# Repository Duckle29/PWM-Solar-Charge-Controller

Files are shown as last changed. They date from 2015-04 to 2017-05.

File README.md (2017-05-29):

# PWM-Solar-Charge-Controller

I have decided to revive this project again. It's gonna be brought back as the PWM10, as It'll be designed to handle 10A, which is a little over a 140W panel.
The Rev2 files are designed using KiCAD

This is an attempt at making an Arduino powered PWM solar charge controller.

The design of this controller is heavily based on Julian Iletts PWM5 controller, which he sadly discontinued.
He however makes some interesting Youtube videos.

  * [Website](http://256.co.uk)
  * [Yoututbe](https://www.youtube.com/user/julius256)

This is **not** done, and there is no protection added to the board as of yet.
This first revision is simply as complete as I could make it, before my patience ran out for that day.
I might very well add the last few bits and bops within a few days.

### No Firmware has been written for this board as of yet
And as such, features and implementations of the hardware has yet to be decided.

### What is special about this spin-off of the PWM5?
This board is:
  * Entirely Arduino compatible, as it uses an ATMega328P
  * Able to measure the voltage of *both* the battery and panel, allowing for alternative control algorithms
  * Fitted with a slot for an NRF24L01+ Transceiver, for sending all available data back and forth / control the PWM charge controller. (After flashing the boot-loader, the solder bridges should be shorted for this feature)
  * Fitted with an RGB LED, that can be controlled to display all sorts of different color combinations and patterns
  * Designed to be cheaply mass produced, with purely SMT parts except for the headers for ISP, NRF and FTDI.

### What needs to be done?
The following things need to be added:
  * Reverse polarity protection
  * Short circuit protection
  * A thorough check of the schematic and board. I slapped this together in one 8 hour sitting, so I'm bound to have missed something / messed something up
  * Firmware needs to be written
  * It needs to be tested in general.
  * Parts need to be checked for availability and pricing. If none are available in the used footprint, a substitute has to be found.

### Additional notes
If I decide the board is ready to go, I will order some assembled boards. If people are interested in some assembled boards, then comment in the issue that I opened for that purpose. I might order some home and send them to you for the price it cost me, and nothing more (that's assembled board cost + shipping)

### Renders:
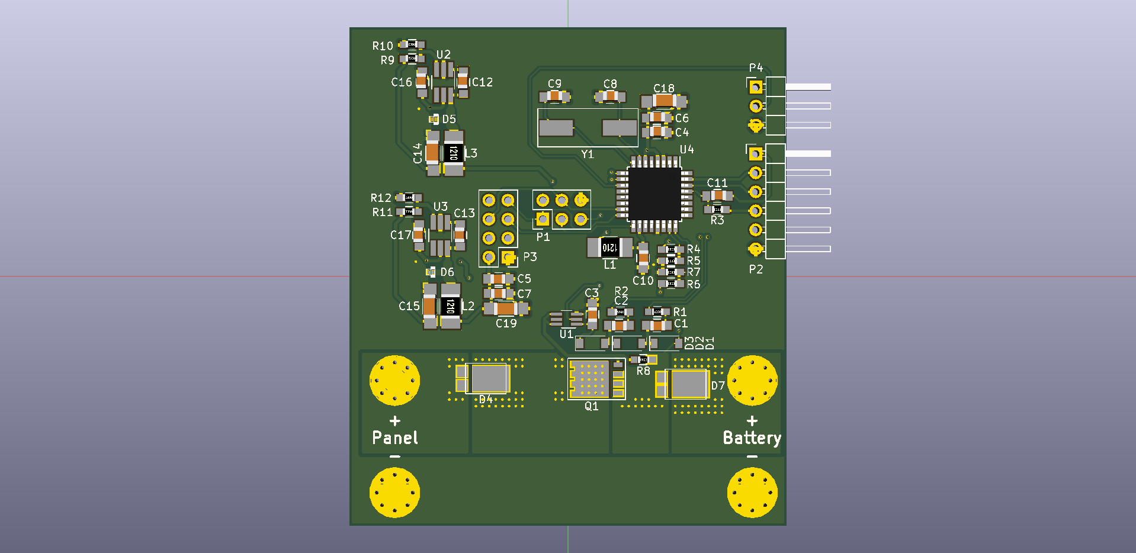
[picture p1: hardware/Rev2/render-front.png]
Front Render

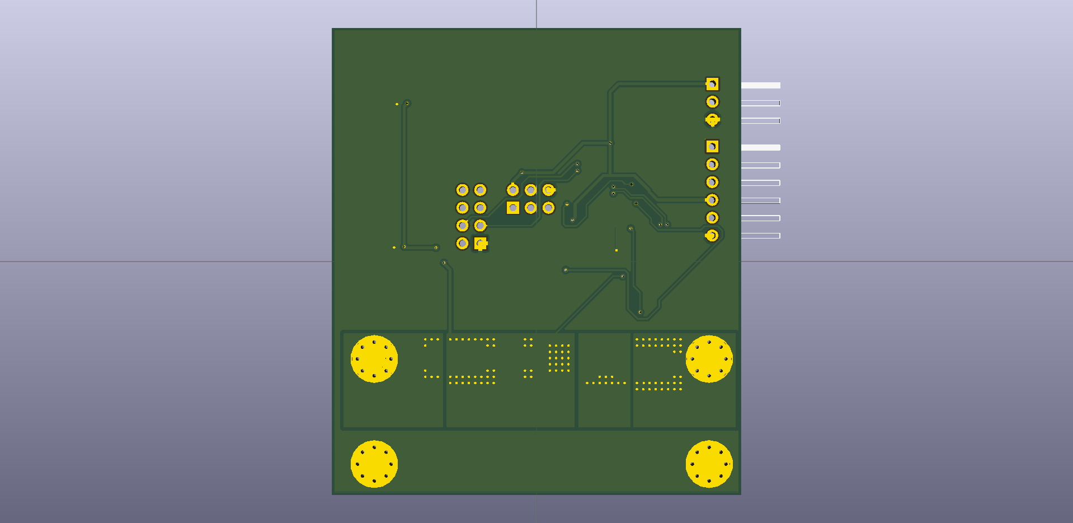
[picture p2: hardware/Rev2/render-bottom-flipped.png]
Flipped Bottom Render

Greetings!

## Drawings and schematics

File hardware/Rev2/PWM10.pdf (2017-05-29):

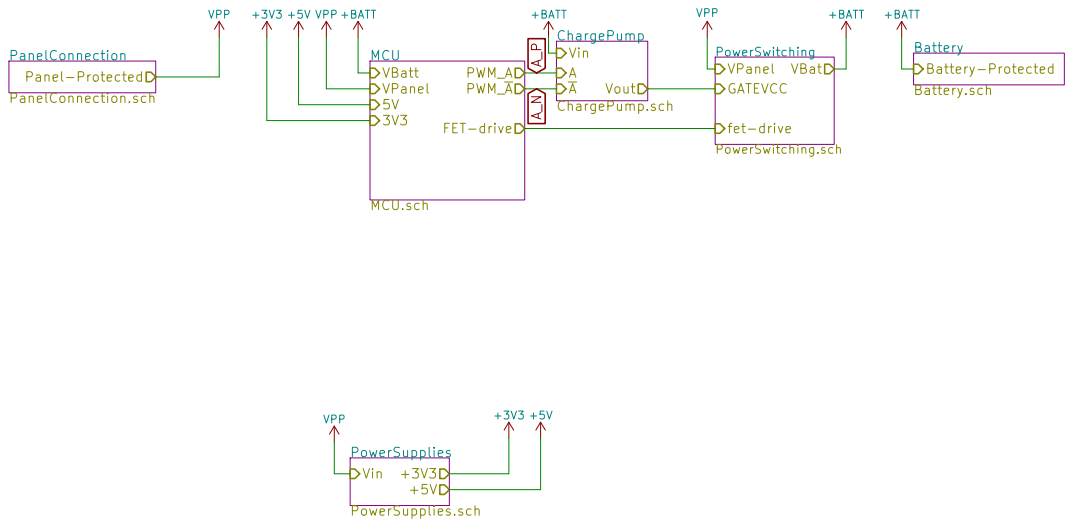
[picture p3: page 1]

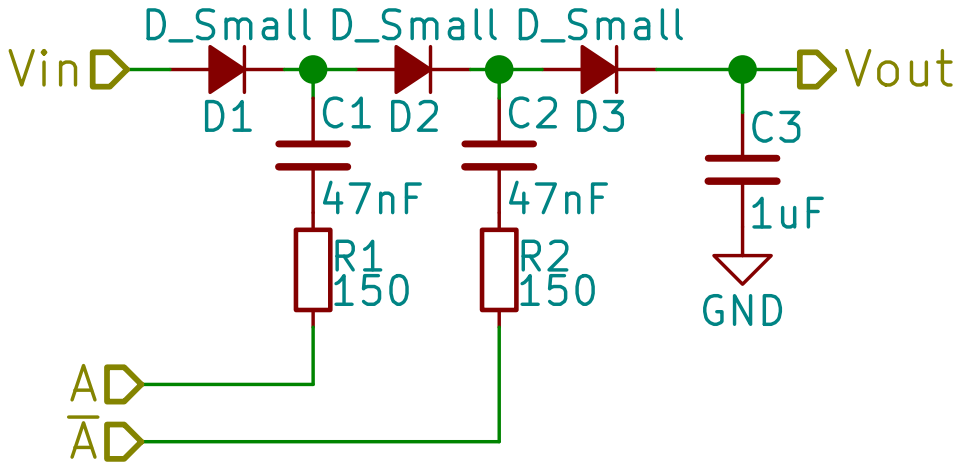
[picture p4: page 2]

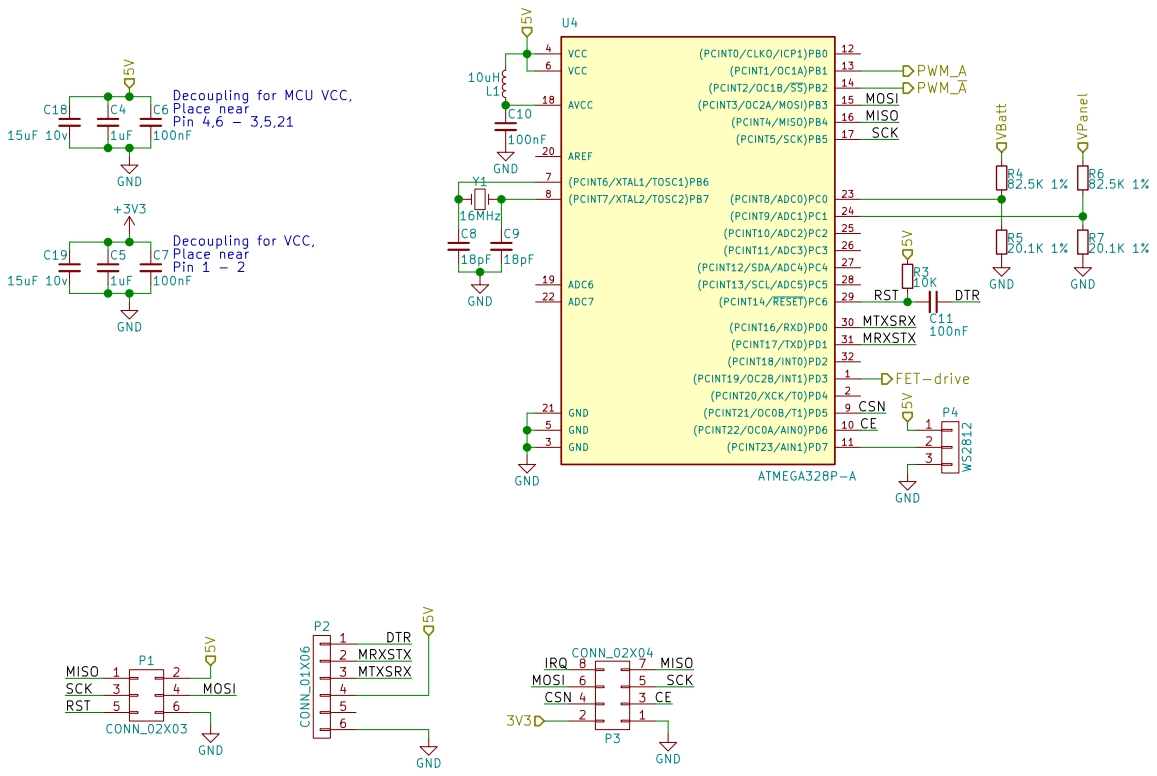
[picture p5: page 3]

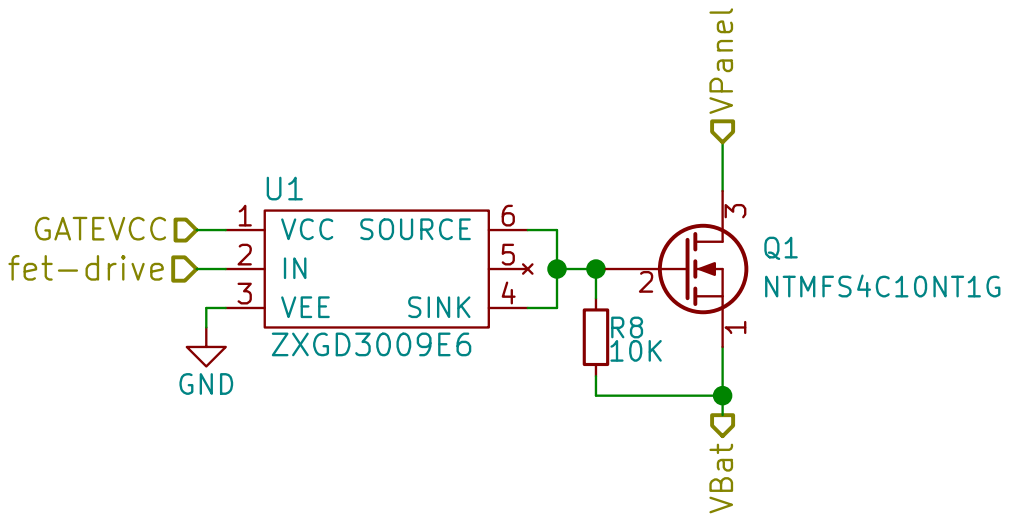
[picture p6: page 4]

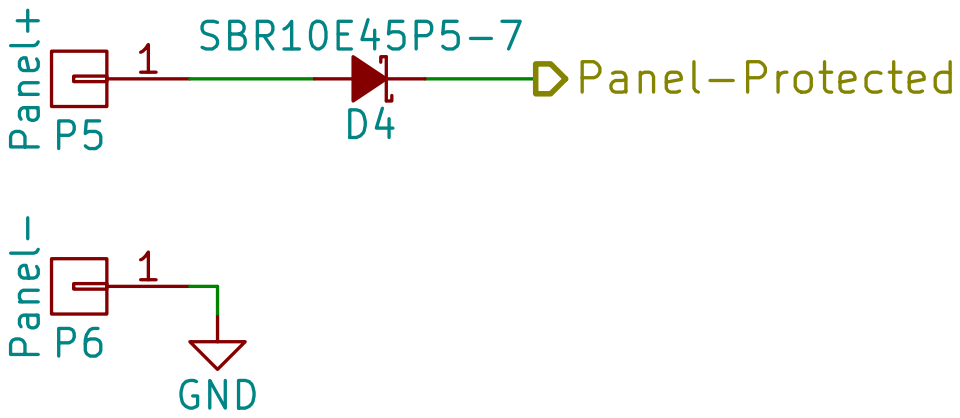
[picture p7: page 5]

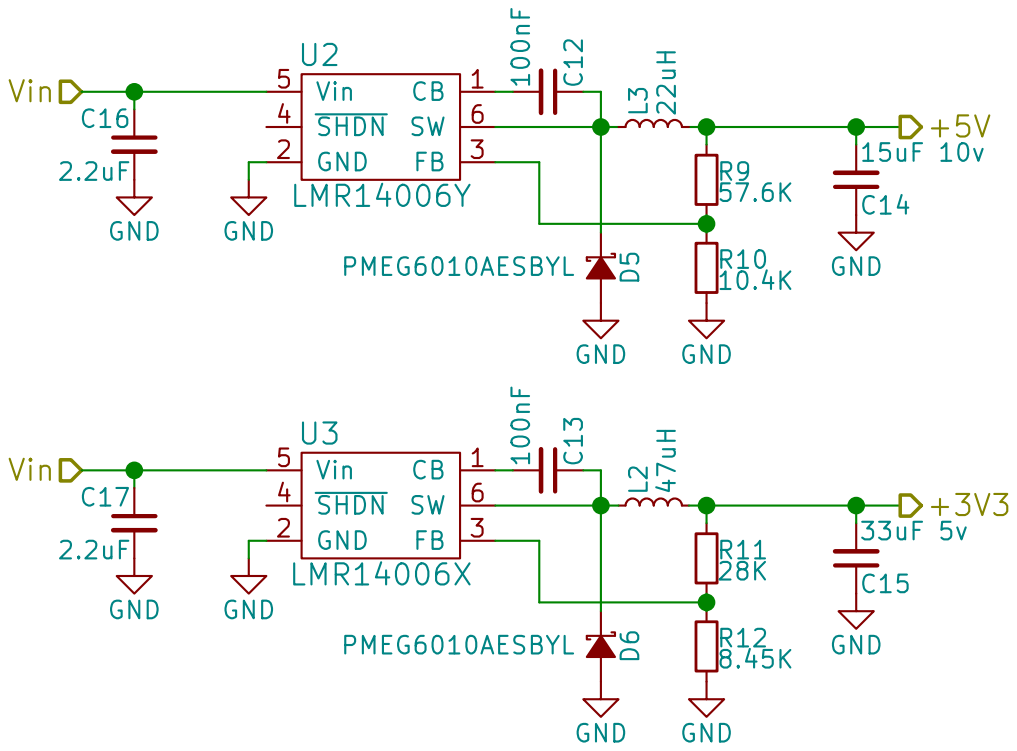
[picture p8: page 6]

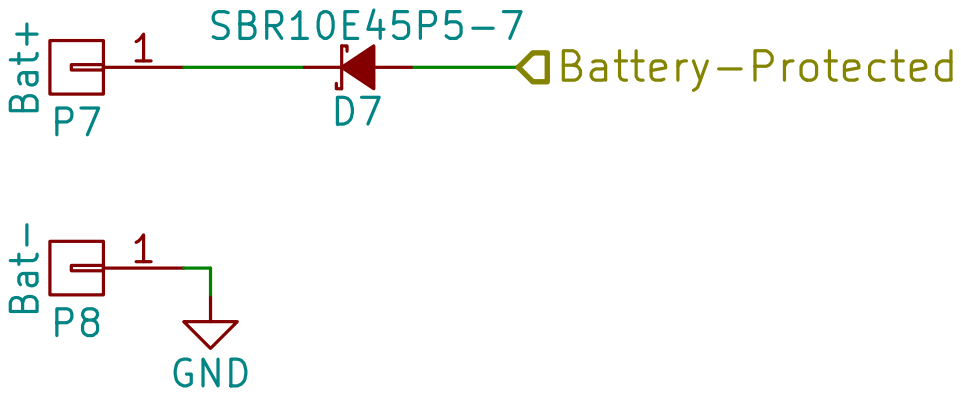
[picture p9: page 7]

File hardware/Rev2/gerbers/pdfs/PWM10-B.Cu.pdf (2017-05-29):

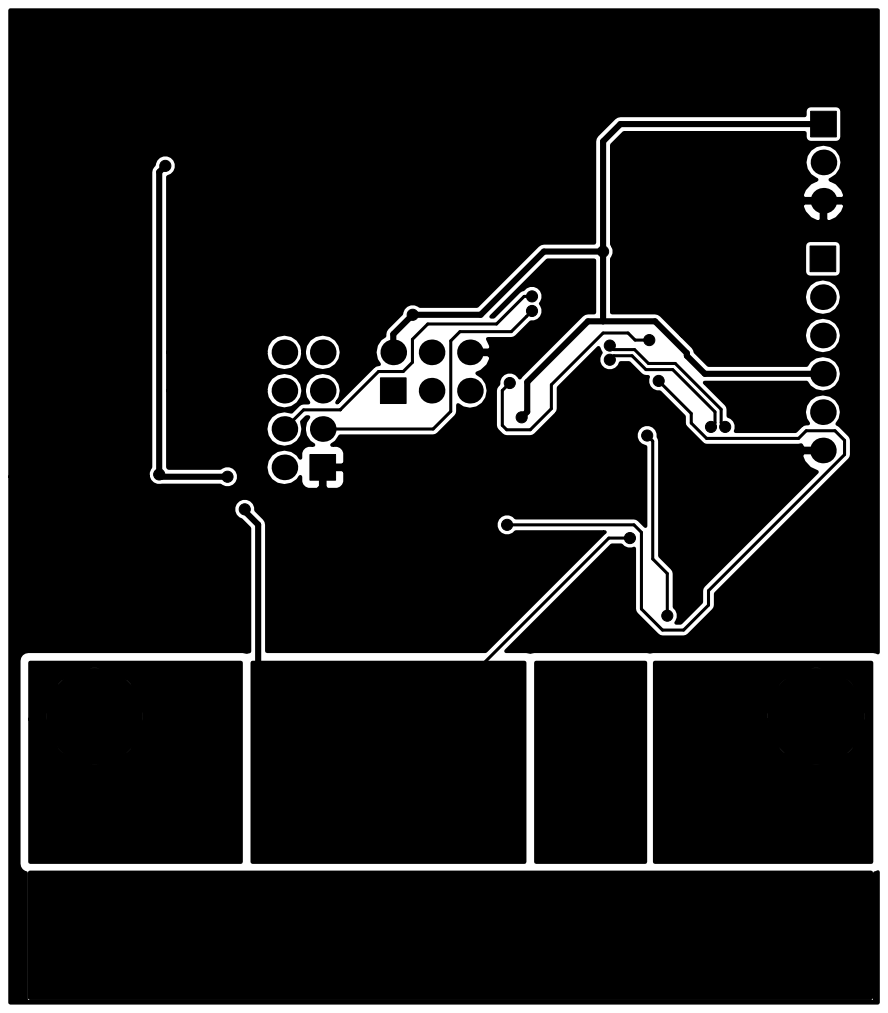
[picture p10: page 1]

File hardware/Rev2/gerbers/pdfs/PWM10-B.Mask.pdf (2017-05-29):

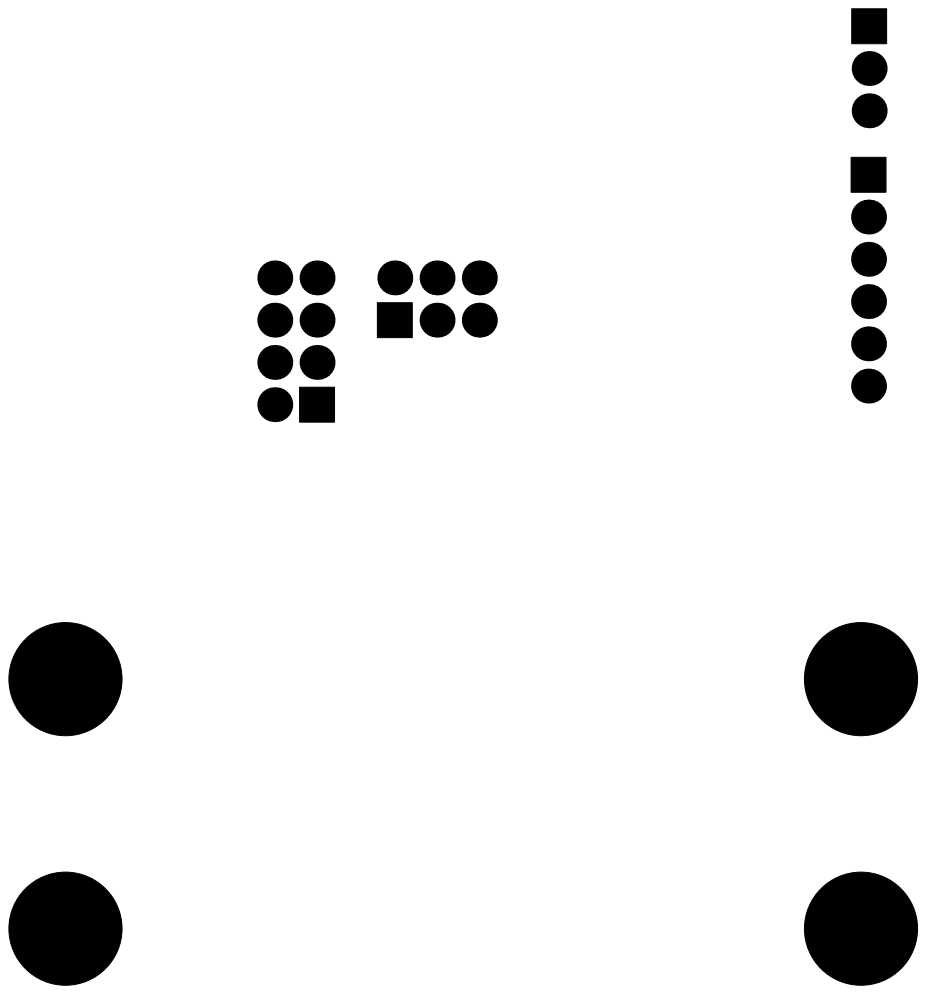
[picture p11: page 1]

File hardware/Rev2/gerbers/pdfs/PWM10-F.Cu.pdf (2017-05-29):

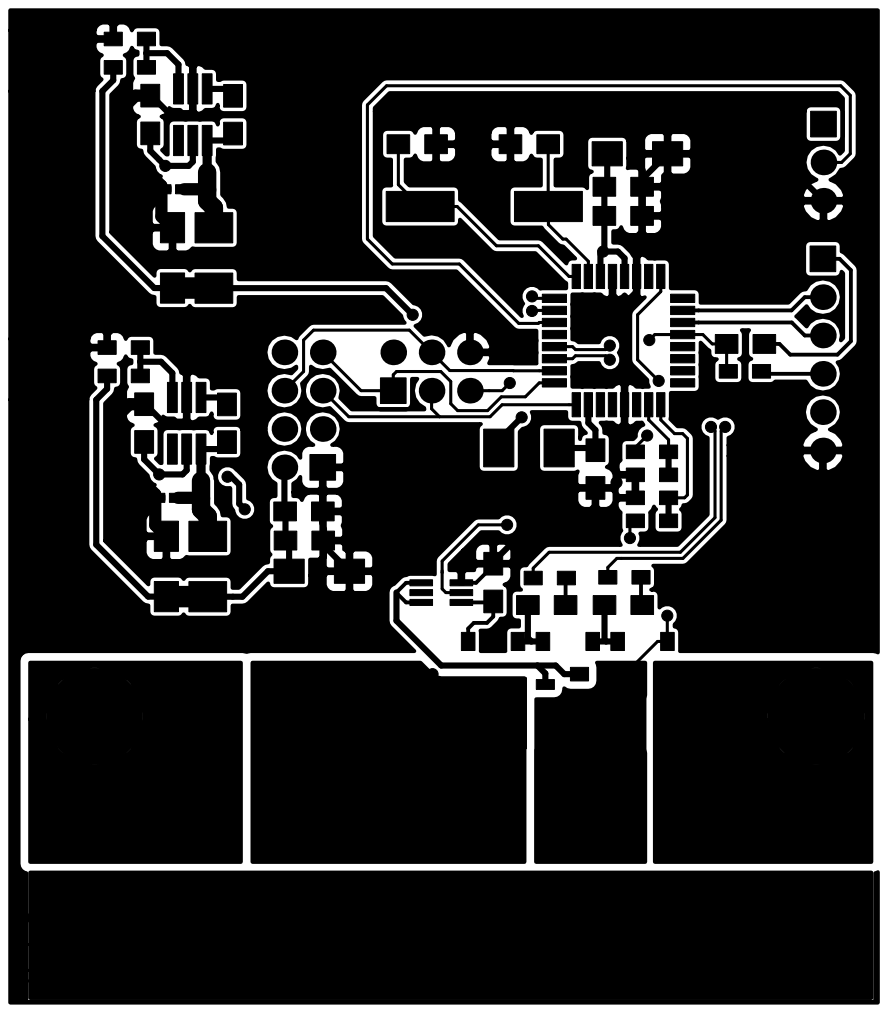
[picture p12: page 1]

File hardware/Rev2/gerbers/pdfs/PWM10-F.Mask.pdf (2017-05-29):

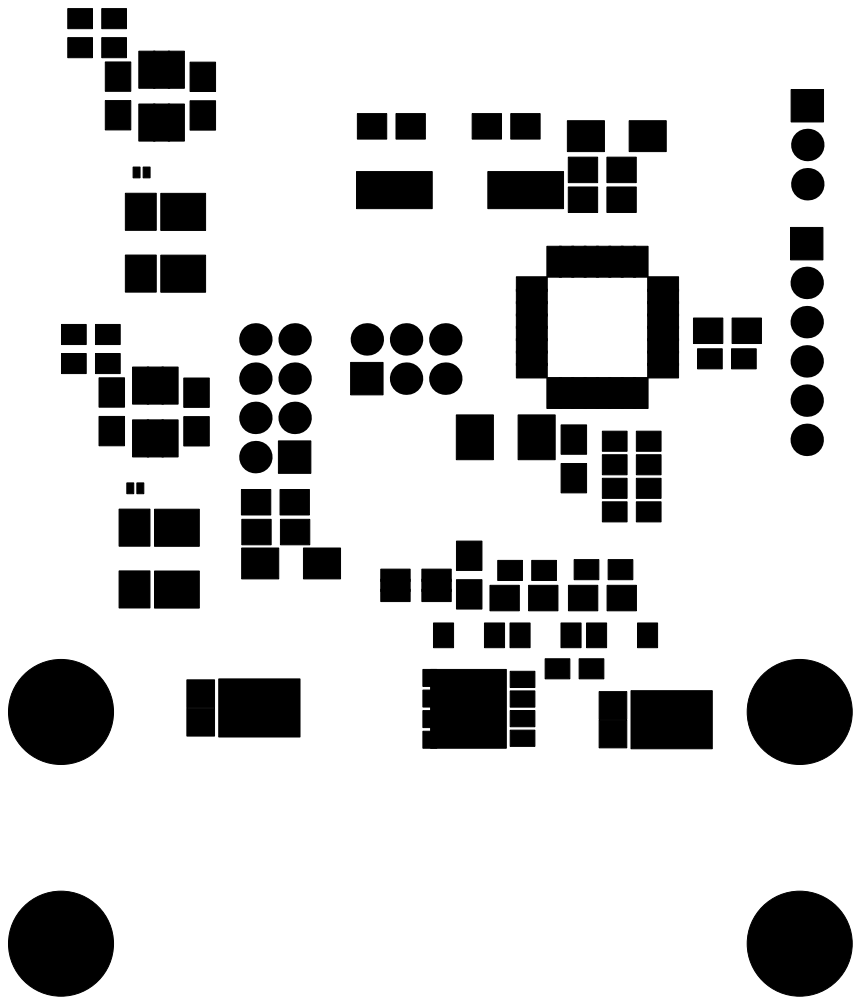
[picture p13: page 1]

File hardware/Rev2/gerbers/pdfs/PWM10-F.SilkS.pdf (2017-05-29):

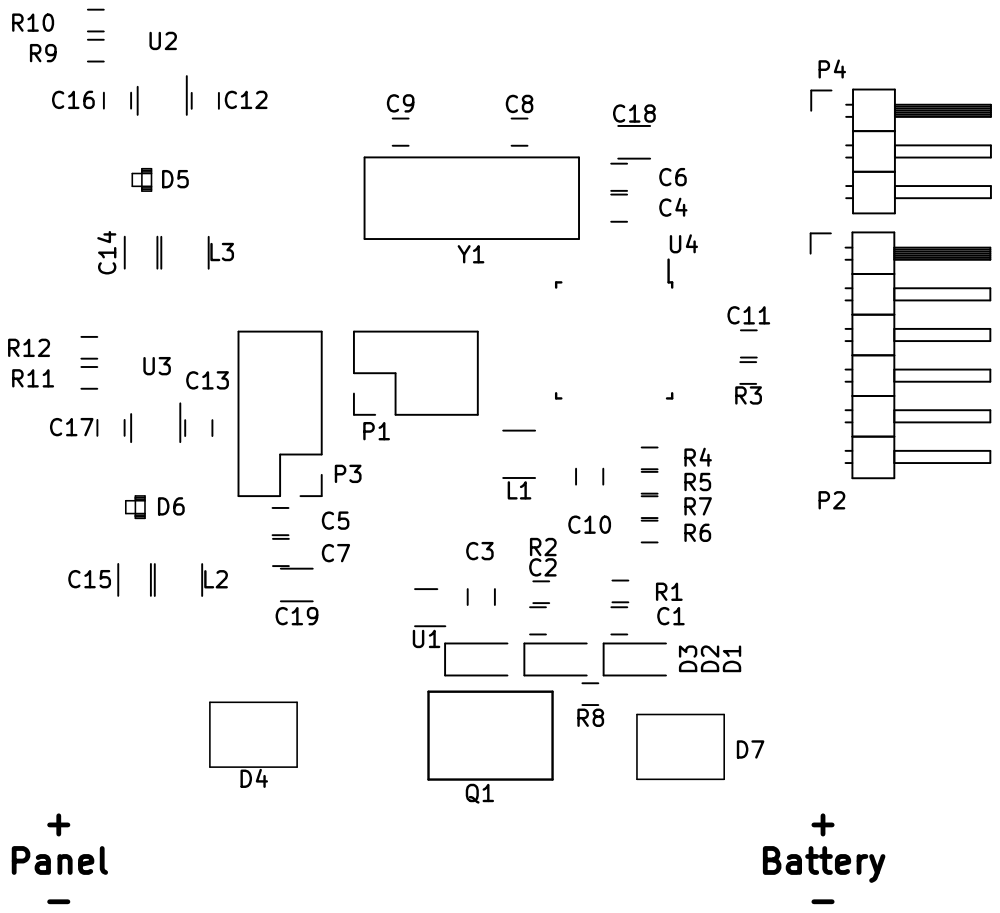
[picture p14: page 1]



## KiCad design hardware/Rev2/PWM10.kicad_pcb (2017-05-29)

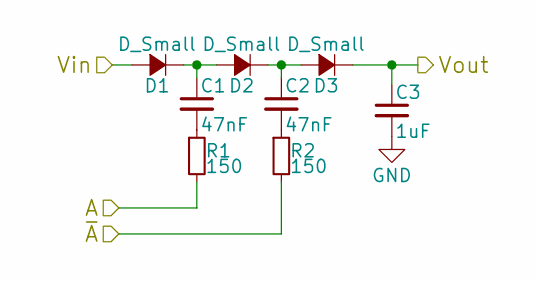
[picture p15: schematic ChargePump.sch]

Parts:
C1, C2: 47nF; C_0805_HandSoldering
C3: 1uF; C_0805_HandSoldering
D1, D2, D3: D_Small; D_SOD-123
R1, R2: 150; R_0603_HandSoldering

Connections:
+BATT: D1.2 (A); also elsewhere on the board
/PowerSwitching/GATEVCC: C3.1, D3.1 (K); also elsewhere on the board
A_N: R2.2; also elsewhere on the board
A_P: R1.2; also elsewhere on the board
GND: C3.2; also elsewhere on the board
unnamed: C1.1, D1.1 (K), D2.2 (A)
unnamed: C1.2, R1.1
unnamed: C2.1, D2.1 (K), D3.2 (A)
unnamed: C2.2, R2.1

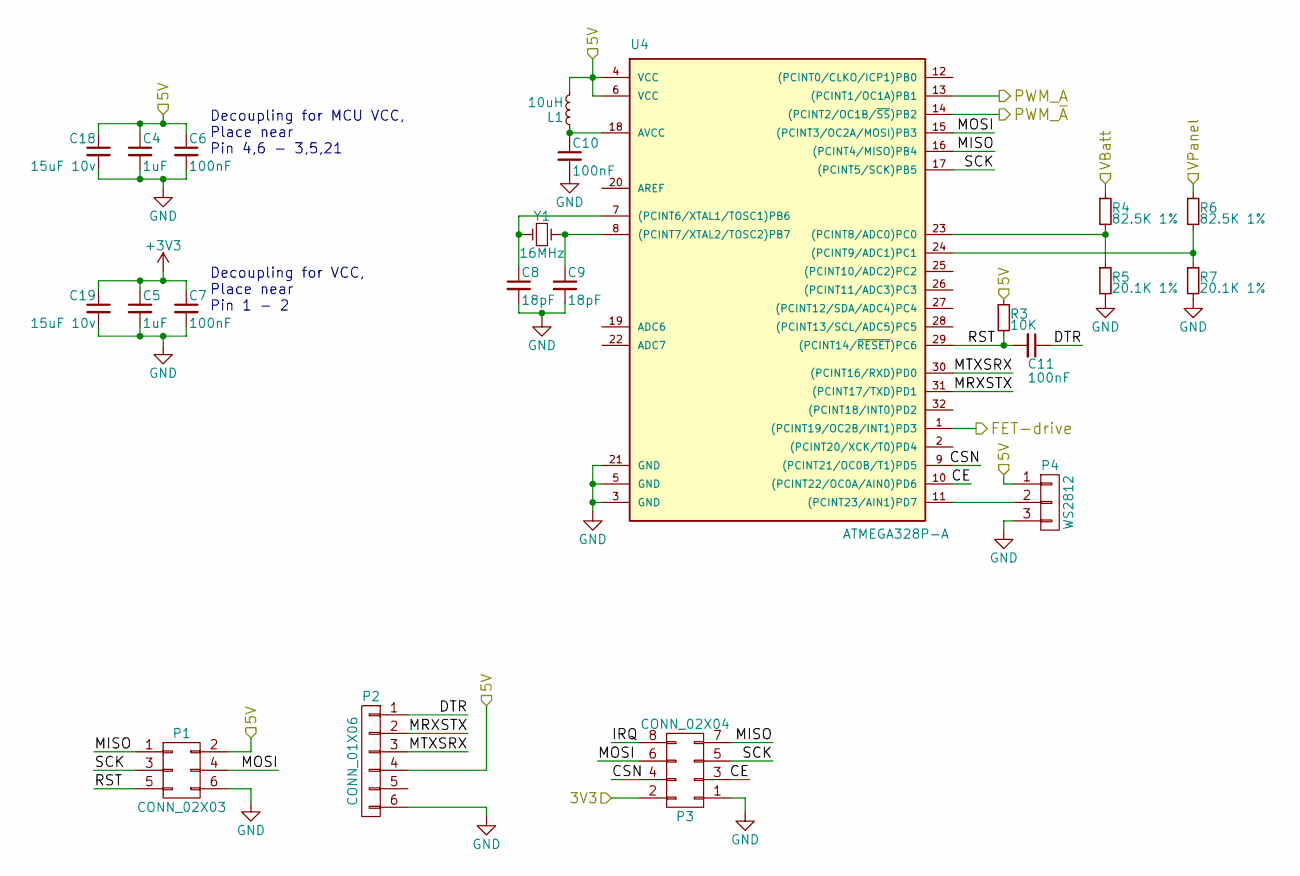
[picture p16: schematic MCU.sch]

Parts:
C4, C5: 1uF; C_0805_HandSoldering
C6, C7, C10, C11: 100nF; C_0805_HandSoldering
C8, C9: 18pF; C_0805_HandSoldering
C18, C19: 15uF 10v; C_1206_HandSoldering
L1: 10uH; R_1210_HandSoldering
P1: CONN_02X03; Pin_Header_Straight_2x03_Pitch2.54mm
P2: CONN_01X06; Pin_Header_Angled_1x06_Pitch2.54mm
P3: CONN_02X04; Pin_Header_Straight_2x04_Pitch2.54mm
P4: WS2812; Pin_Header_Angled_1x03_Pitch2.54mm
R3: 10K; R_0603_HandSoldering
R4, R6: 82.5K 1%; R_0603_HandSoldering
R5, R7: 20.1K 1%; R_0603_HandSoldering
U4: ATMEGA328P-A; TQFP-32_7x7mm_Pitch0.8mm
Y1: 16MHz; Crystal_SMD_HC49-SD

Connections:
+3V3: C5.1, C7.1, C19.1, P3.2; also elsewhere on the board
+5V: C4.1, C6.1, C18.1, L1.2, P1.2, P2.4, P4.1, R3.1, U4.4 (VCC), U4.6 (VCC); also elsewhere on the board
+BATT: R4.1; also elsewhere on the board
/MCU/CE: P3.3, U4.10 ((PCINT22/OC0A/AIN0)PD6)
/MCU/CSN: P3.4, U4.9 ((PCINT21/OC0B/T1)PD5)
/MCU/DTR: C11.1, P2.1
/MCU/FET-drive: U4.1 ((PCINT19/OC2B/INT1)PD3); also elsewhere on the board
/MCU/IRQ: P3.8
/MCU/MISO: P1.1, P3.7, U4.16 ((PCINT4/MISO)PB4)
/MCU/MOSI: P1.4, P3.6, U4.15 ((PCINT3/OC2A/MOSI)PB3)
/MCU/MRXSTX: P2.2, U4.31 ((PCINT17/TXD)PD1)
/MCU/MTXSRX: P2.3, U4.30 ((PCINT16/RXD)PD0)
/MCU/RST: C11.2, P1.5, R3.2, U4.29 ((PCINT14/~RESET~)PC6)
/MCU/SCK: P1.3, P3.5, U4.17 ((PCINT5/SCK)PB5)
A_N: U4.14 ((PCINT2/OC1B/~SS~)PB2); also elsewhere on the board
A_P: U4.13 ((PCINT1/OC1A)PB1); also elsewhere on the board
GND: C4.2, C5.2, C6.2, C7.2, C8.2, C9.2, C10.2, C18.2, C19.2, P1.6, P2.6, P3.1, P4.3, R5.2, R7.2, U4.3 (GND), U4.5 (GND), U4.21 (GND); also elsewhere on the board
unnamed: C8.1, U4.7 ((PCINT6/XTAL1/TOSC1)PB6), Y1.1
unnamed: C9.1, U4.8 ((PCINT7/XTAL2/TOSC2)PB7), Y1.2
unnamed: C10.1, L1.1, U4.18 (AVCC)
unnamed: P4.2, U4.11 ((PCINT23/AIN1)PD7)
unnamed: R4.2, R5.1, U4.23 ((PCINT8/ADC0)PC0)
unnamed: R6.2, R7.1, U4.24 ((PCINT9/ADC1)PC1)
VPP: R6.1; also elsewhere on the board

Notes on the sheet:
Decoupling for MCU VCC, Place near Pin 4,6 - 3,5,21
Decoupling for VCC, Place near Pin 1 - 2

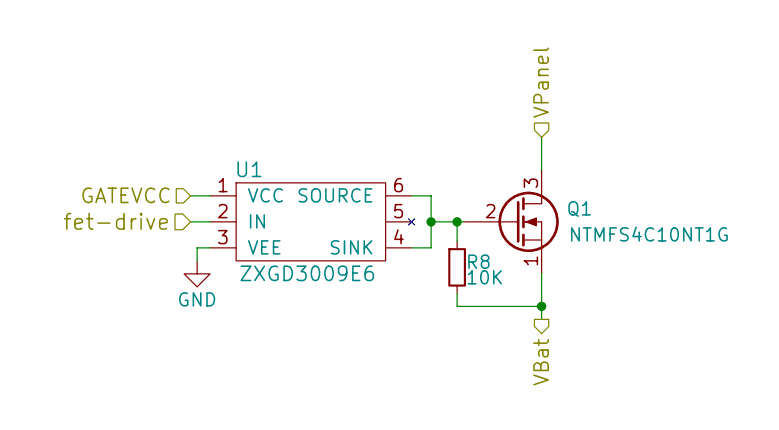
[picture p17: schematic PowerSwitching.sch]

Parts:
Q1: NTMFS4C10NT1G; PG-TDSON-8
R8: 10K; R_0603_HandSoldering
U1: ZXGD3009E6; SOT-363_SC-70-6_Handsoldering

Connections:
+BATT: Q1.1 (S), R8.2; also elsewhere on the board
/MCU/FET-drive: U1.2 (IN); also elsewhere on the board
/PowerSwitching/GATEVCC: U1.1 (VCC); also elsewhere on the board
GND: U1.3 (VEE); also elsewhere on the board
unnamed: Q1.2 (G), R8.1, U1.4 (SINK), U1.6 (SOURCE)
VPP: Q1.3 (D); also elsewhere on the board

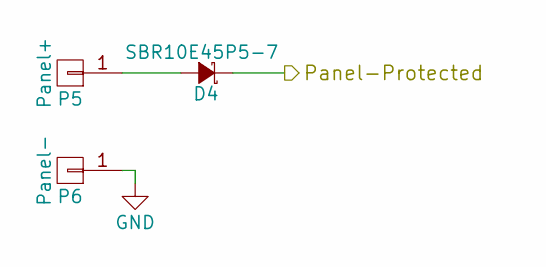
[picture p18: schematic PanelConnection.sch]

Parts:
D4: SBR10E45P5-7; PowerDI5
P5: Panel+; MountingHole_3.2mm_M3_Pad_Via
P6: Panel-; MountingHole_3.2mm_M3_Pad_Via

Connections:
GND: P6.1; also elsewhere on the board
unnamed: D4.2 (A), P5.1
VPP: D4.1 (K); also elsewhere on the board

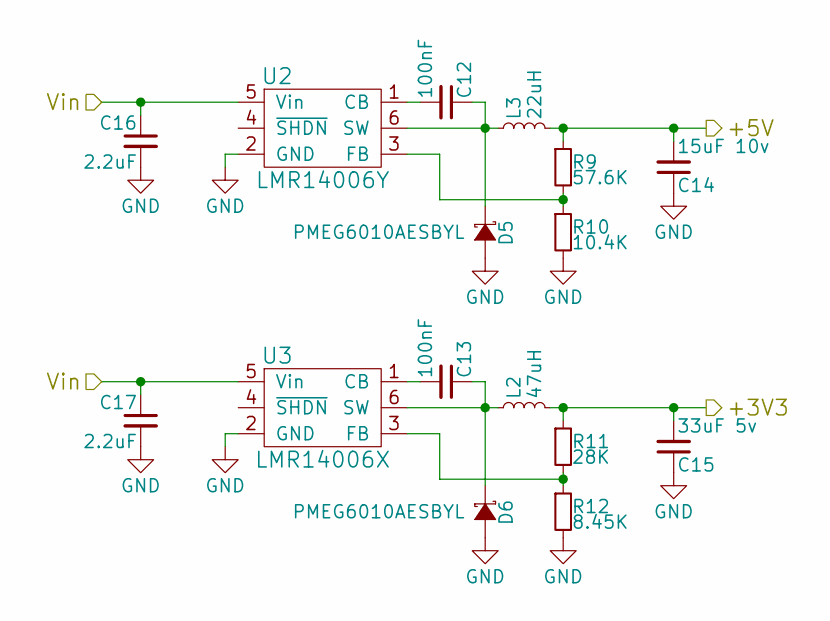
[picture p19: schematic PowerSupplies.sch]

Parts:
C12, C13: 100nF; C_0805_HandSoldering
C14: 15uF 10v; C_1206_HandSoldering
C15: 33uF 5v; C_1206_HandSoldering
C16, C17: 2.2uF; C_0805_HandSoldering
D5, D6: PMEG6010AESBYL; SOD-993
L2: 47uH; R_1210_HandSoldering; Part CBC3225T470MR
L3: 22uH; R_1210_HandSoldering; Part CBC3225T220MR
R9: 57.6K; R_0603_HandSoldering
R10: 10.4K; R_0603_HandSoldering
R11: 28K; R_0603_HandSoldering
R12: 8.45K; R_0603_HandSoldering
U2: LMR14006Y; TSOT-23-6_MK06A_HandSoldering
U3: LMR14006X; TSOT-23-6_MK06A_HandSoldering

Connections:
+3V3: C15.2, L2.2, R11.1; also elsewhere on the board
+5V: C14.2, L3.2, R9.1; also elsewhere on the board
GND: C14.1, C15.1, C16.2, C17.2, D5.2 (A), D6.2 (A), R10.2, R12.2, U2.2 (GND), U3.2 (GND); also elsewhere on the board
unnamed: C12.1, D5.1 (K), L3.1, U2.6 (SW)
unnamed: C12.2, U2.1 (CB)
unnamed: C13.1, D6.1 (K), L2.1, U3.6 (SW)
unnamed: C13.2, U3.1 (CB)
unnamed: R9.2, R10.1, U2.3 (FB)
unnamed: R11.2, R12.1, U3.3 (FB)
VPP: C16.1, C17.1, U2.5 (Vin), U3.5 (Vin); also elsewhere on the board

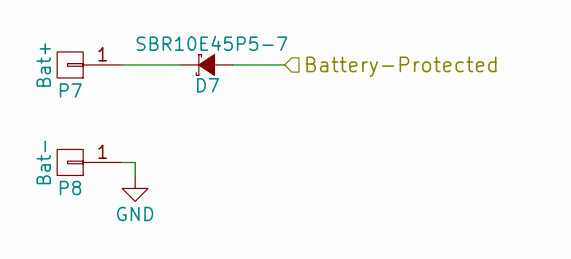
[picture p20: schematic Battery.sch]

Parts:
D7: SBR10E45P5-7; PowerDI5
P7: Bat+; MountingHole_3.2mm_M3_Pad_Via
P8: Bat-; MountingHole_3.2mm_M3_Pad_Via

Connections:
+BATT: D7.2 (A); also elsewhere on the board
GND: P8.1; also elsewhere on the board
unnamed: D7.1 (K), P7.1

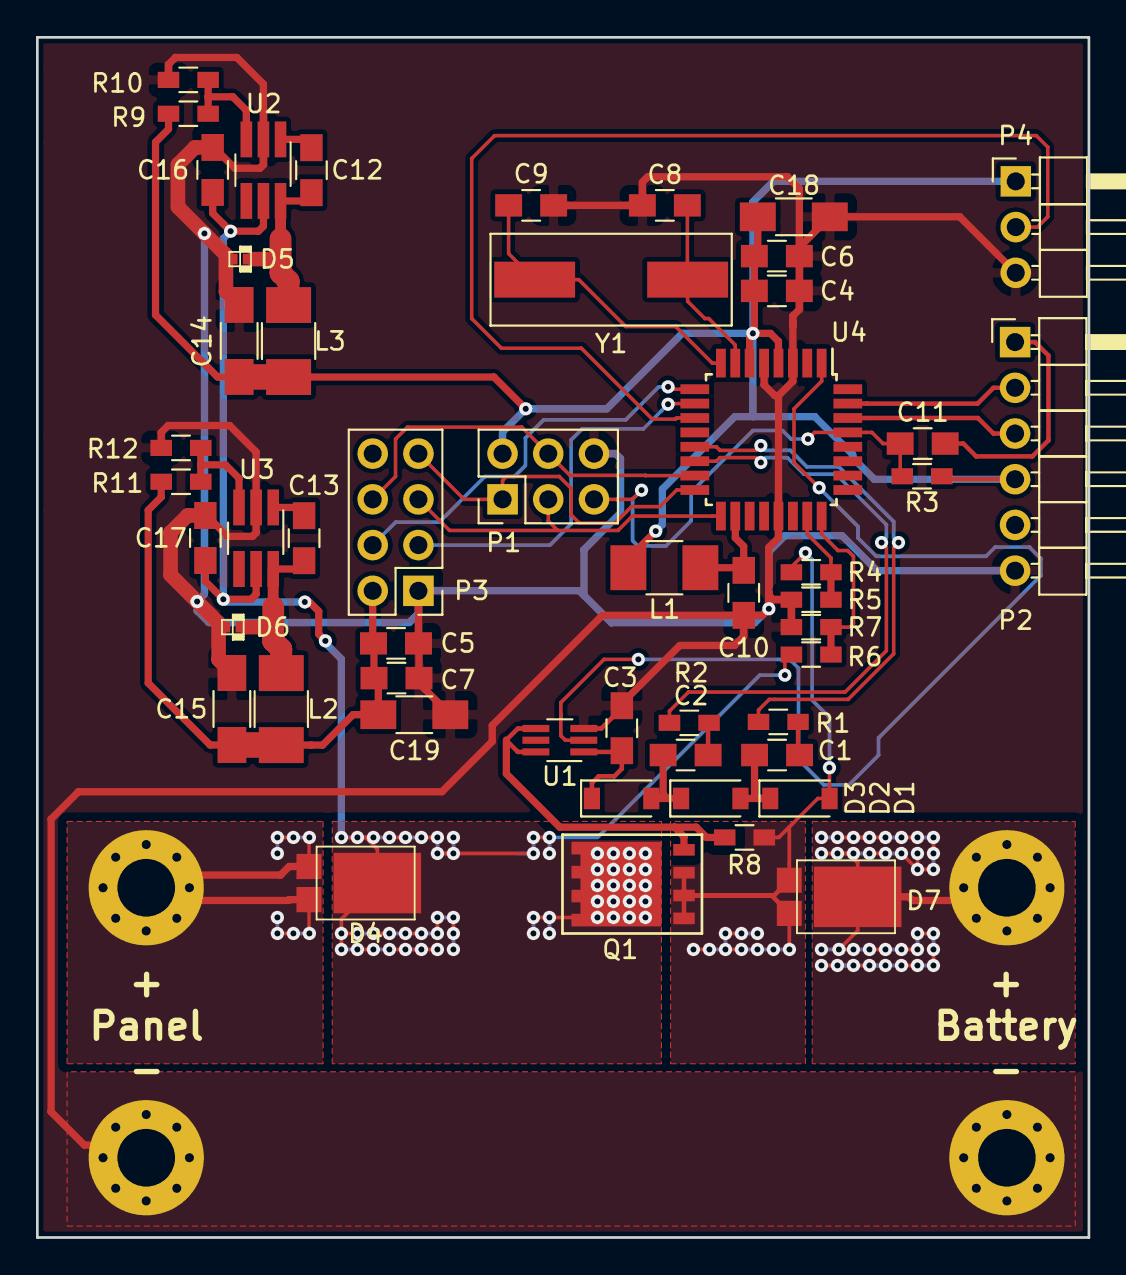
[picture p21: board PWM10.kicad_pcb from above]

Board: 2 copper layers, 58.4 x 66.7 mm, 55 parts (0 on the bottom side), 37 nets.

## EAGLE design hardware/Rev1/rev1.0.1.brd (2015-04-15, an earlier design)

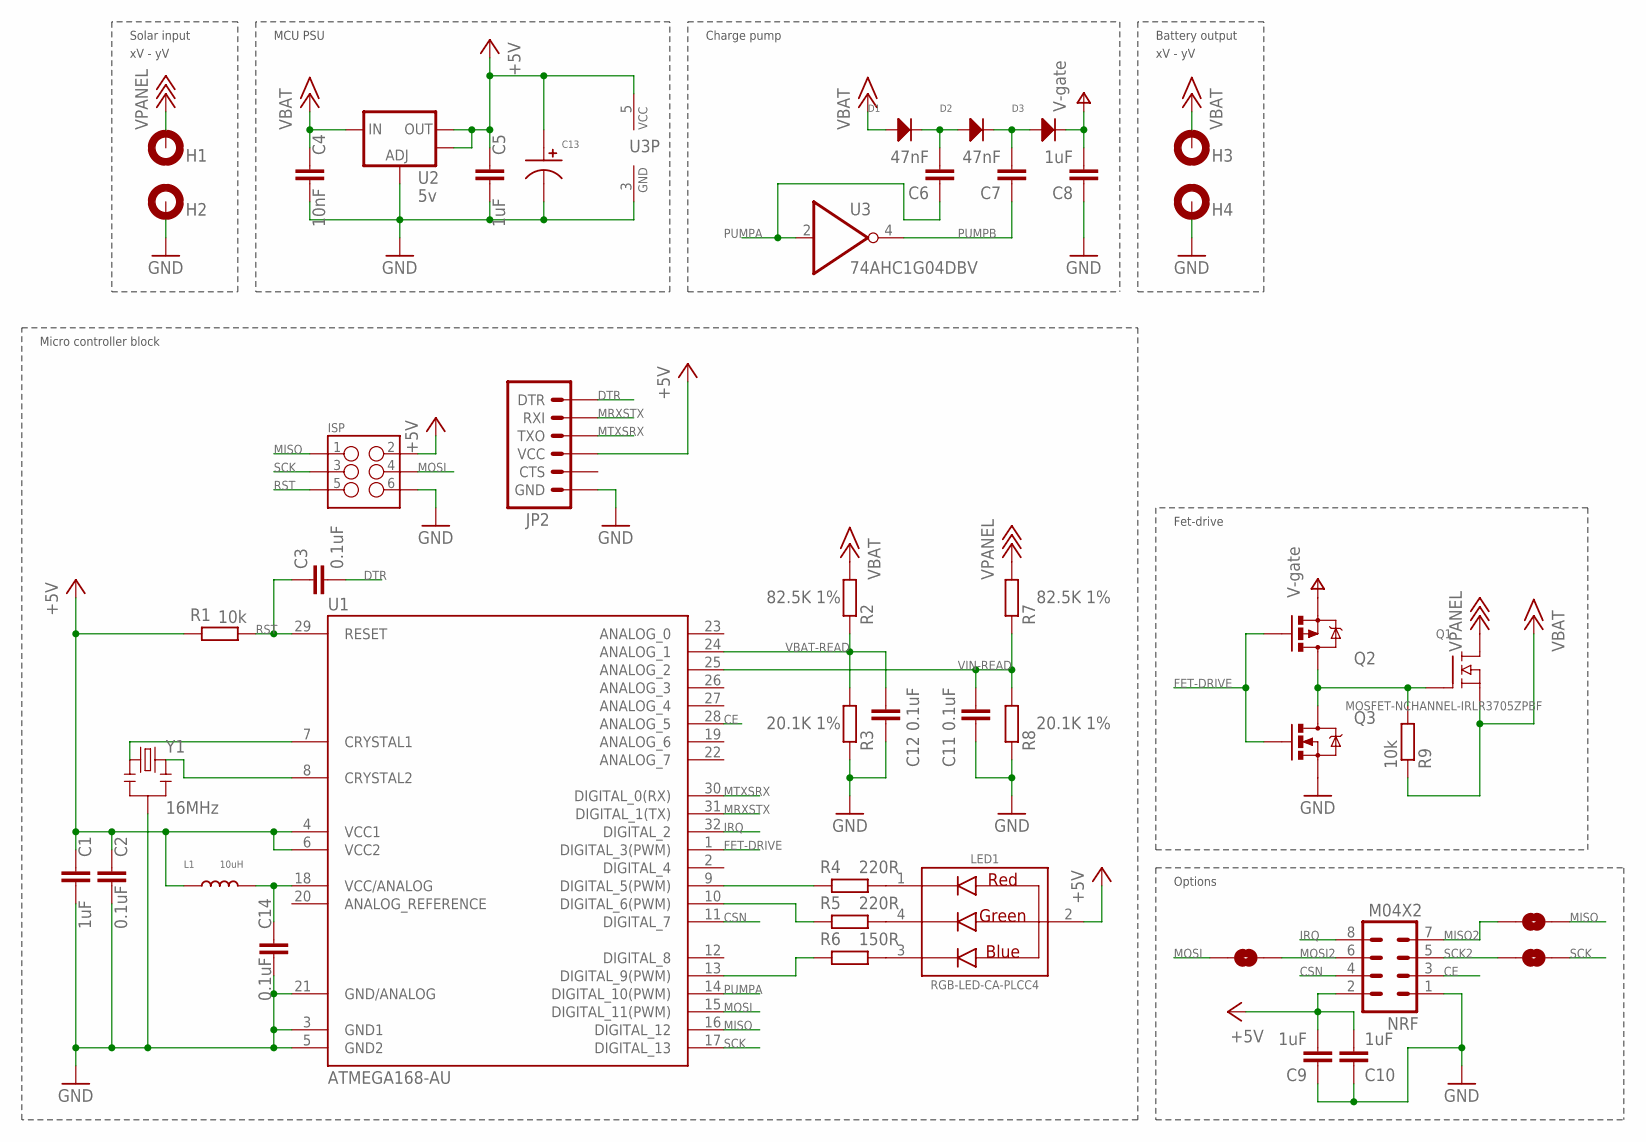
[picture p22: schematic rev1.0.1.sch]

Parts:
C1, C5, C8, C9, C10: 1uF; C0603K
C2, C3, C11, C12, C14: 0.1uF; C0603K
C4: 10nF; C0603K
C6, C7: 47nF; C0603K
C13: CAPACITOR_P_4MM; CP4MM
D1, D2, D3: DIODE_SOD-123; SOD-123
H1, H2, H3, H4: MOUNT-PAD-ROUND3.0; 3,0-PAD
ISP: M03X22X3_SILK_SM; 2X3
JP2: ARDUINO_SERIAL_PROGRAMLOCK; 1X06_LOCK
L1: 10uH; L1210
LED1: RGB-LED-CA-PLCC4; PLCC4
NRF: M04X2; 2X4
Q1: MOSFET-NCHANNEL-IRLR3705ZPBF; DPAK
Q2: MOSFET-PCHANNEL; SOT23
Q3: MOSFET-NCHANNELBSS138; SOT23
R1, R9: 10k; R0603
R2, R7: 82.5K 1%; R0603
R3, R8: 20.1K 1%; R0603
R4, R5: 220R; R0603
R6: 150R; R0603
SJ2, SJ5, SJ6: SOLDERJUMPERNO; SJ_2S-NO
U1: ATMEGA168-AU; TQFP32-08
U2: 5v; SOT223
U3: 74AHC1G04DBV; SOT23-5
Y1: 16MHz; RESONATOR-SMD

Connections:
+5V: C1.1, C2.1, C5.1, C9.2, C10.2, C13.P$1, ISP.2, JP2.4 (VCC), L1.P$1, LED1.2 (CA), NRF.2, R1.2, U1.4 (VCC1), U1.6 (VCC2), U2.2 (OUT), U2.4 (OUT), U3.5 (VCC)
+15V: C4.1, D1.ANODE, H3.B3,0, Q1.2 (S), R2.2, R9.1, U2.3 (IN)
+18V: H1.B3,0, Q1.TAB (D), R7.2
CE: NRF.3, U1.28 (ANALOG_5)
CSN: NRF.4, U1.11 (DIGITAL_7)
DTR: C3.2, JP2.1 (DTR)
FET-DRIVE: Q2.1 (G), Q3.1 (G), U1.1 (DIGITAL_3(PWM))
FET-PUMP: Q1.1 (G), Q2.3 (D), Q3.3 (D), R9.2
GND: C1.2, C2.2, C4.2, C5.2, C8.1, C9.1, C10.1, C11.1, C12.1, C13.P$2, C14.2, H2.B3,0, H4.B3,0, ISP.6, JP2.6 (GND), NRF.1, Q3.2 (S), R3.1, R8.1, U1.3 (GND1), U1.5 (GND2), U1.21 (GND/ANALOG), U2.1 (ADJ), U3.3 (GND), Y1.2
IRQ: NRF.8, U1.32 (DIGITAL_2)
MISO: ISP.1, SJ6.2, U1.16 (DIGITAL_12)
MISO2: NRF.7, SJ6.1
MOSI: ISP.4, SJ2.1, U1.15 (DIGITAL_11(PWM))
MOSI2: NRF.6, SJ2.2
MRXSTX: JP2.2 (RXI), U1.31 (DIGITAL_1(TX))
MTXSRX: JP2.3 (TXO), U1.30 (DIGITAL_0(RX))
unnamed: U1.8 (CRYSTAL2), Y1.3
unnamed: U1.7 (CRYSTAL1), Y1.1
unnamed: R4.2, U1.9 (DIGITAL_5(PWM))
unnamed: LED1.4 (GC), R5.1
unnamed: LED1.1 (RC), R4.1
unnamed: LED1.3 (BC), R6.1
unnamed: R5.2, U1.10 (DIGITAL_6(PWM))
unnamed: C7.2, D2.CATHODE, D3.ANODE
unnamed: R6.2, U1.13 (DIGITAL_9(PWM))
unnamed: C6.2, D1.CATHODE, D2.ANODE
unnamed: C14.1, L1.P$2, U1.18 (VCC/ANALOG)
PUMPA: C6.1, U1.14 (DIGITAL_10(PWM)), U3.2 (I)
PUMPB: C7.1, U3.4 (O)
RST: C3.1, ISP.5, R1.1, U1.29 (RESET)
SCK: ISP.3, SJ5.2, U1.17 (DIGITAL_13)
SCK2: NRF.5, SJ5.1
V+: C8.2, D3.CATHODE, Q2.2 (S)
VBAT-READ: C12.2, R2.1, R3.2, U1.24 (ANALOG_1)
VIN-READ: C11.2, R7.1, R8.2, U1.25 (ANALOG_2)

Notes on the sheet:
Solar input
xV - yV
Micro controller block
Options
MCU PSU
Battery output
Fet-drive
Charge pump

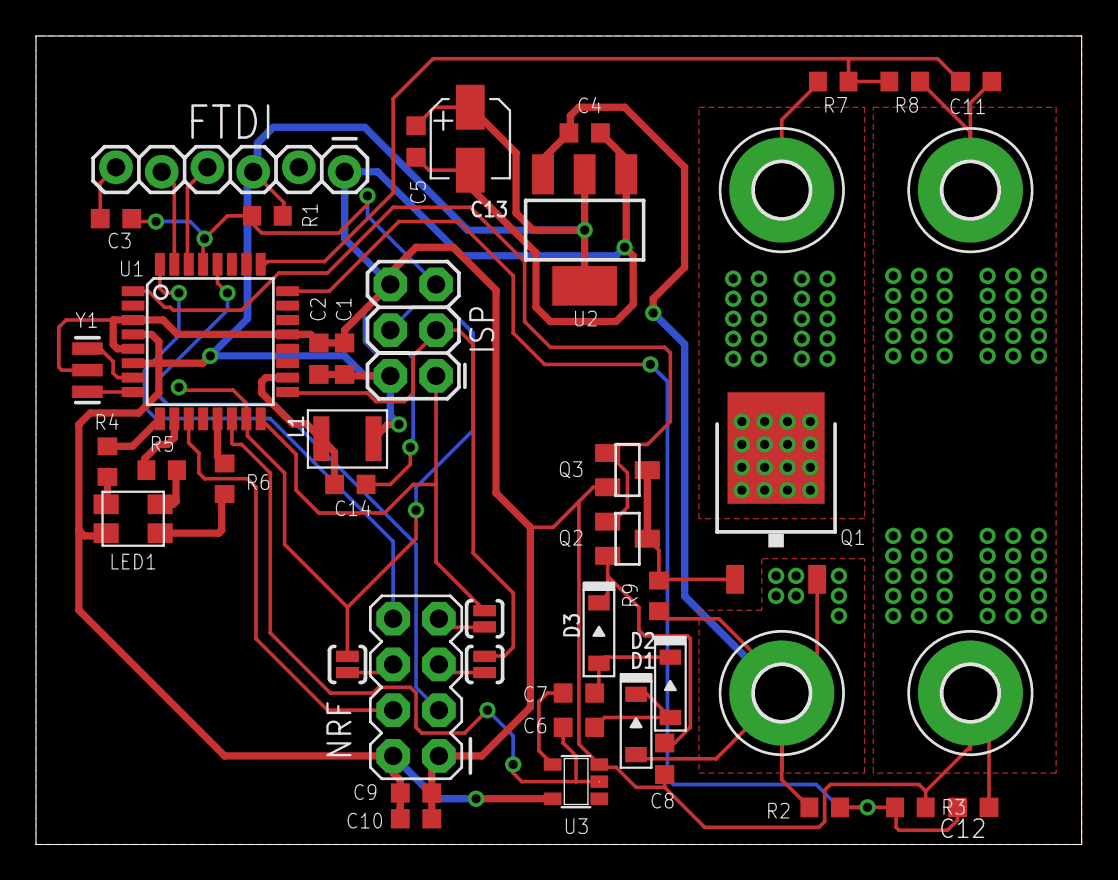
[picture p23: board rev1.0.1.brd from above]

Board: 2 copper layers, 58.1 x 44.9 mm, 45 parts (0 on the bottom side), 35 nets.

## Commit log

2015-04-15 Added charge pump for v-gate
    [rev1.brd, rev1.sch]
2015-04-15 Schematic pre-finished. Needs values added
    [rev1.brd, rev1.sch]
2015-04-15 Board laid out
    [rev1.brd, rev1.sch]
2015-04-15 Fixing LDO input pin
    [rev1.brd, rev1.sch]
2015-04-15 Added copper pour, sorted silk screen
    [rev1.brd, rev1.sch]
2015-04-15 Added PDF of both schematic and board
2015-04-15 Added dimentions to the board
    [rev1.brd]
2015-04-15 Made a hardware and firmware folder
    [rev1.brd, rev1.sch]
2015-04-15 Propperly filtered AVCC
    [rev1.0.1.brd, rev1.0.1.sch]
2015-04-15 Fixed copper ground pour
    [rev1.0.1.brd]
2017-05-23 Finished schematic of Rev2
    [BatteryConnection.sch, ChargePump.sch, MCU.sch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]
2017-05-23 doing some stupid shit to rename rev1
    [rev1.0.1.brd, rev1.0.1.sch]
2017-05-23 Renamed rev1 to Rev1
    [rev1.0.1.brd, rev1.0.1.sch]
2017-05-29 created PCB and gerbers
    [Battery.sch, BatteryConnection.sch, ChargePump.sch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]

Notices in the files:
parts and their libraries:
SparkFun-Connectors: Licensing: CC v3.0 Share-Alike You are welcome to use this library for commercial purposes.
